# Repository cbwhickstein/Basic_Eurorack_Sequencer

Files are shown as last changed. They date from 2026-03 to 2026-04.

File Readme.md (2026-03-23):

# Eurorack CD4017 10-Steps Sequencer
This Repo containes a simple 10 Step sequencer for the Eurorack Modular standard.

## Schematic
./KiCad/Sequencer/Schematic.pdf


## PCB
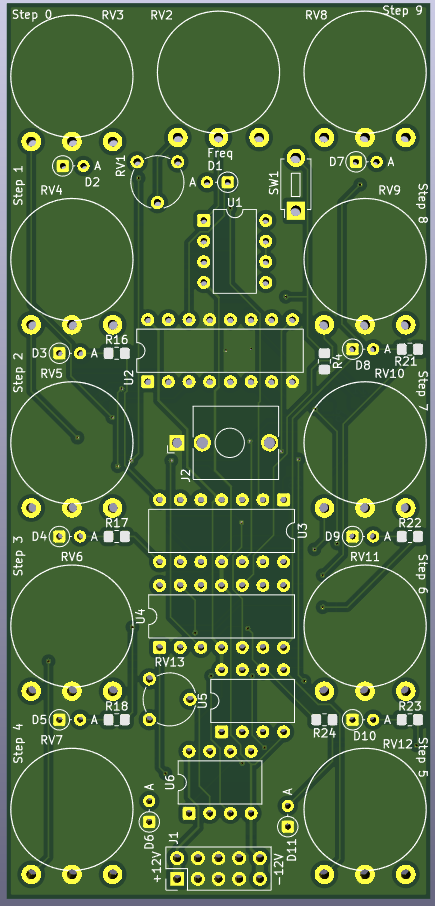
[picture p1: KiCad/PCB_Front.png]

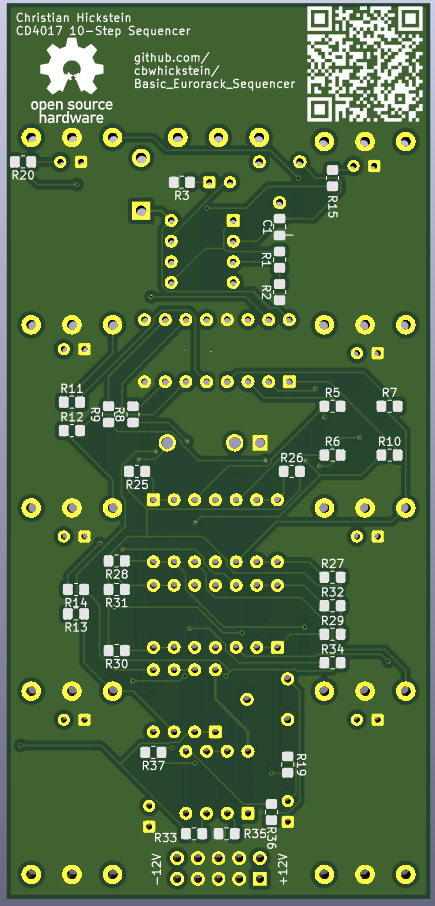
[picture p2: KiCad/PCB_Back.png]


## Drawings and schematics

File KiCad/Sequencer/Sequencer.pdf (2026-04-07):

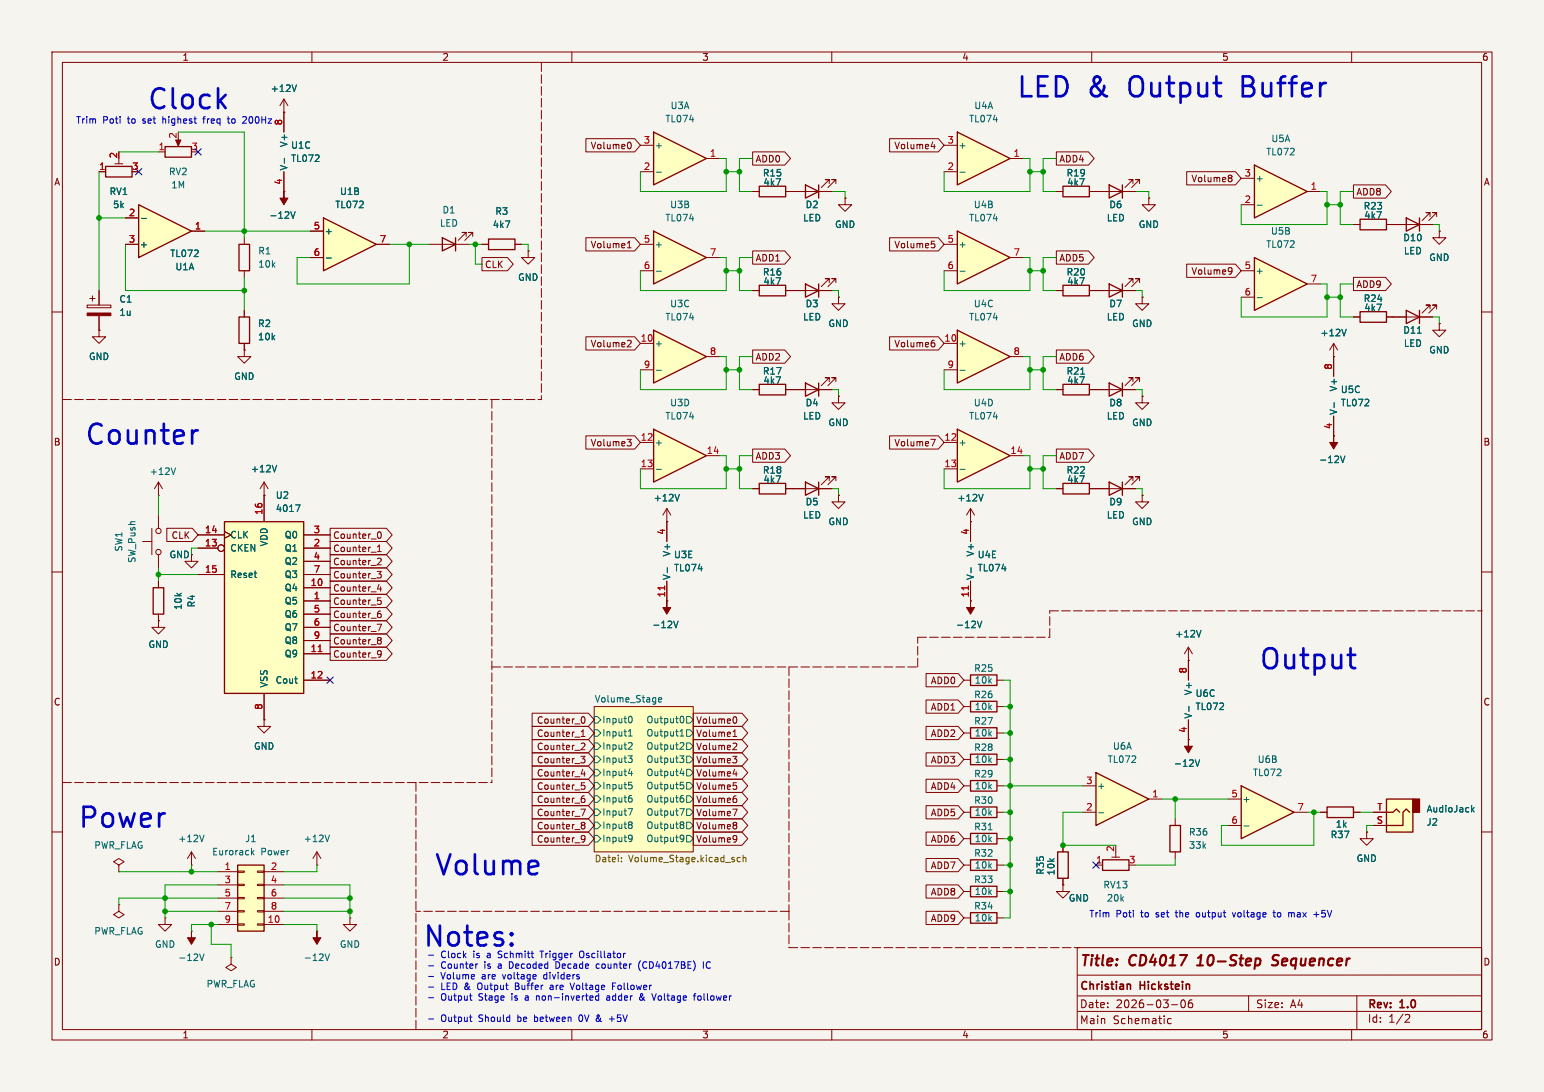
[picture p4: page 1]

Trim Poti to set highest freq to 200Hz

- Output Should be between 0V & +5V Counter

8 Q0 3 Q1 2 Q2 4 Q3 7 Q4 10 Q5 1 Q6 5 Q7 6 Q8 9 Q9 11 Cout 12 GND 10k R4 GND GND

Trim Poti to set the output voltage to max +5V Output

- Clock is a Schmitt Trigger Oscillator
- Volume are voltage dividers
- LED & Output Buffer are Voltage Follower

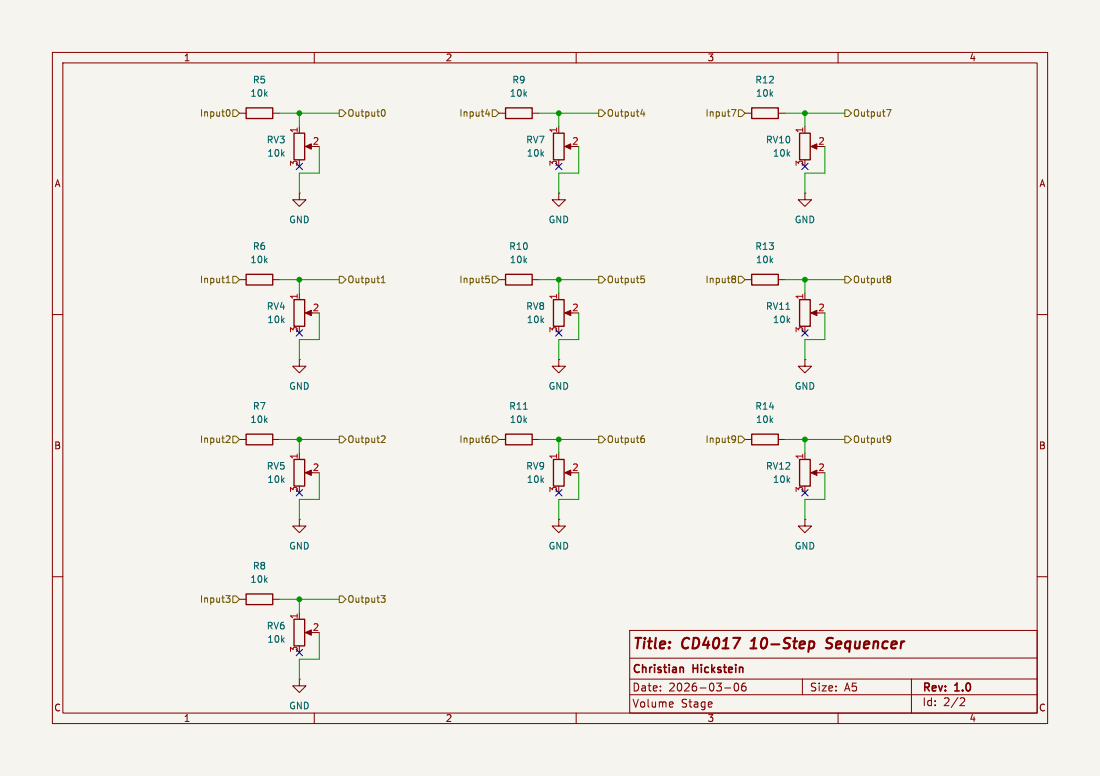
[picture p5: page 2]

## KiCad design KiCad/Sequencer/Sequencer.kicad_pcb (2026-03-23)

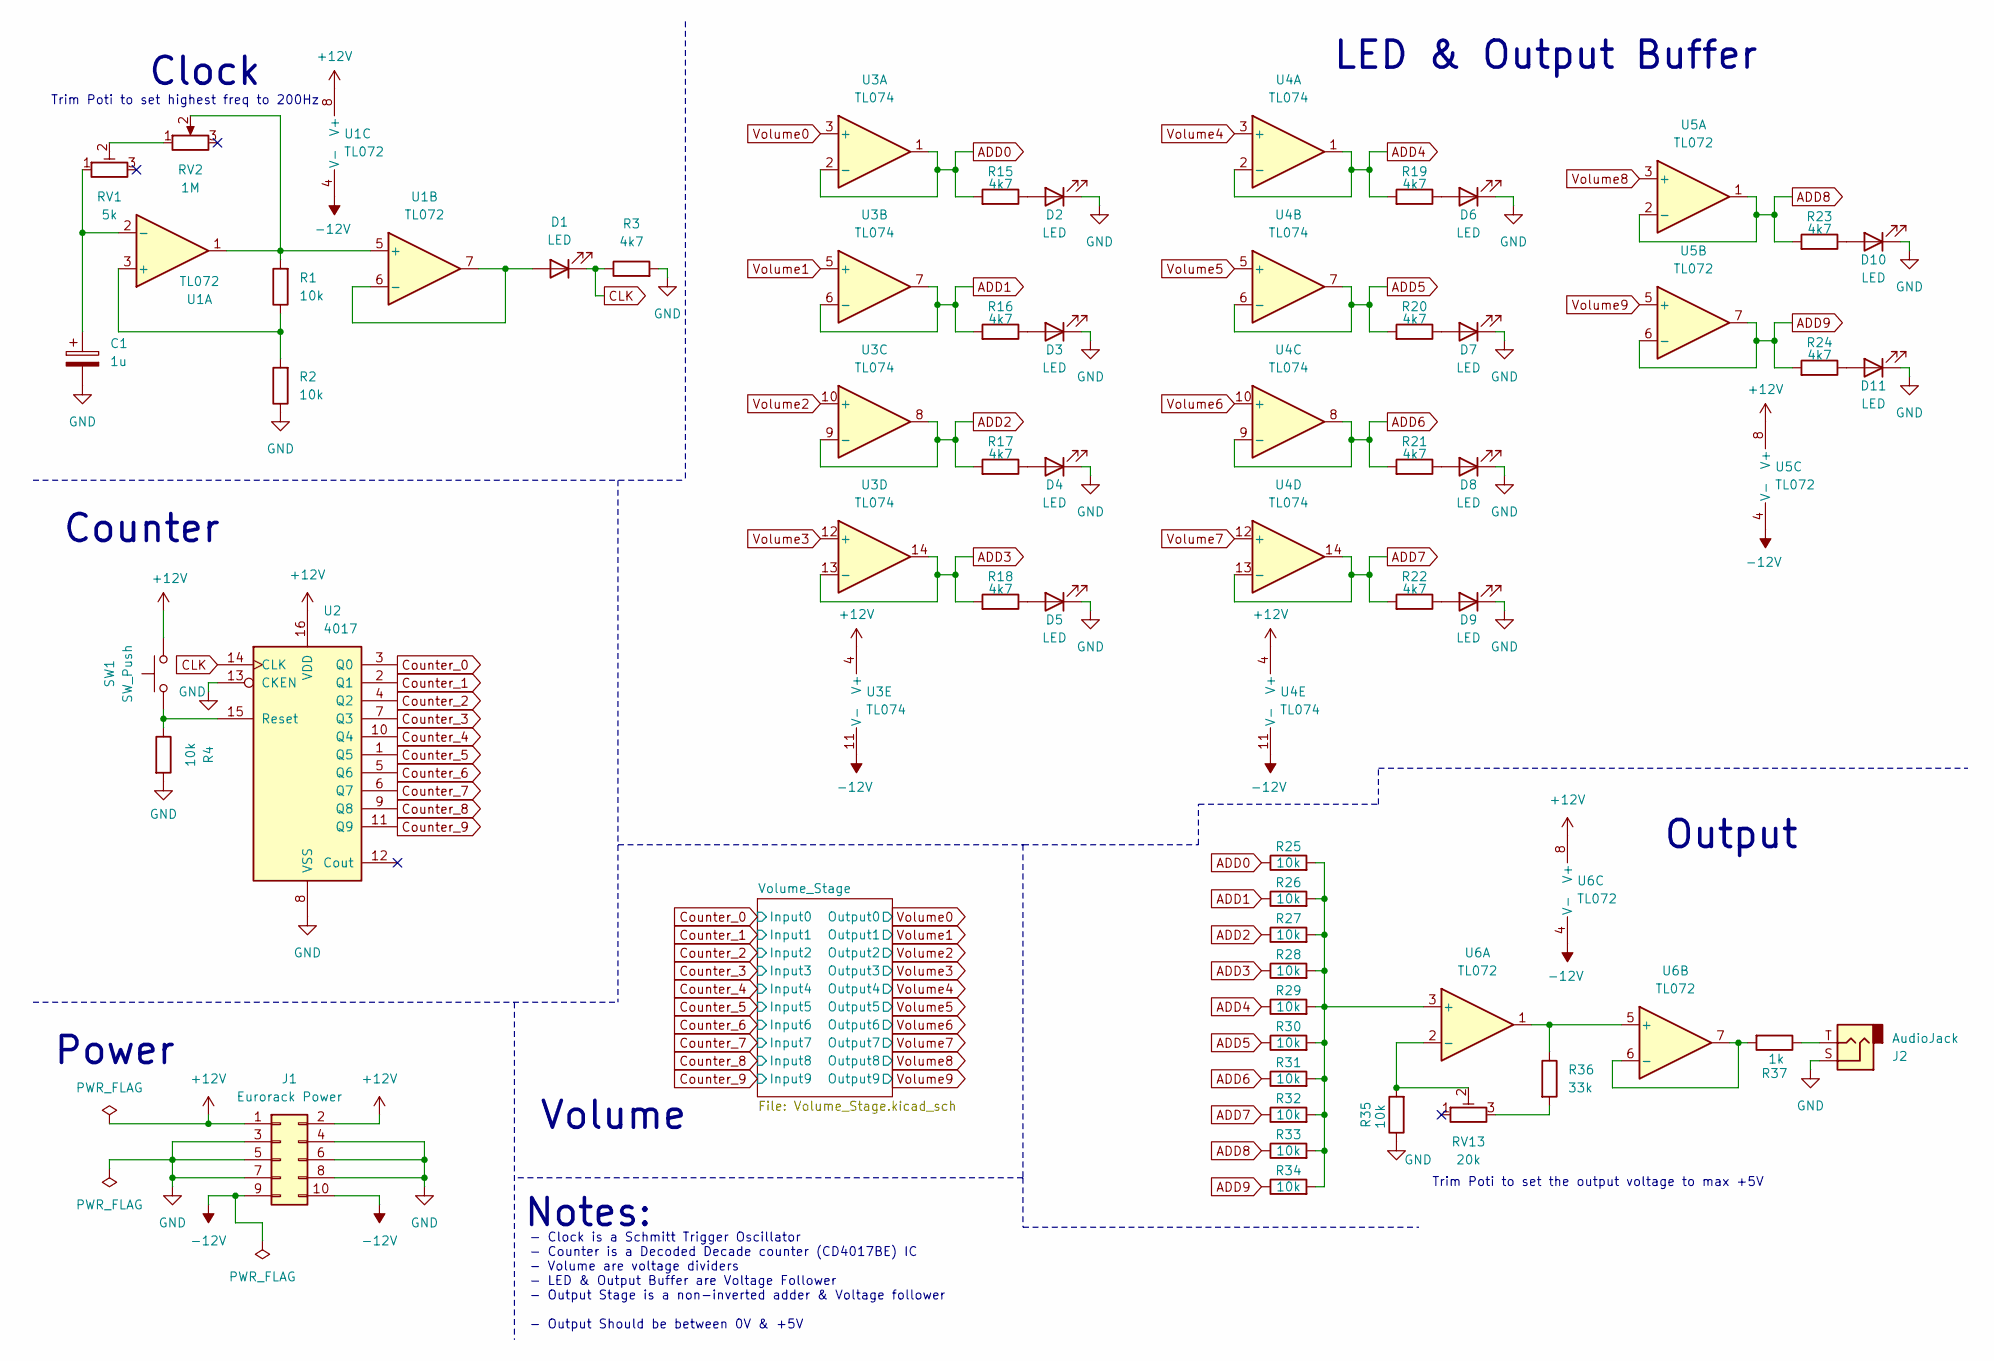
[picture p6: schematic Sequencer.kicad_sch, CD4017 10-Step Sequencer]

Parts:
C1: 1u; C_0805_2012Metric_Pad1.18x1.45mm_HandSolder
D1, D2, D3, D4, D5, D6, D7, D8, D9, D10, D11: LED; D_DO-34_SOD68_P2.54mm_Vertical_AnodeUp
J1: Eurorack Power; PinHeader_2x05_P2.54mm_Vertical
J2: AudioJack; Jack_3.5mm_QingPu_WQP-PJ398SM_Vertical_CircularHoles
R1, R2, R4, R25, R26, R27, R28, R29, R30, R31, R32, R33, R34, R35: 10k; R_0805_2012Metric_Pad1.20x1.40mm_HandSolder
R3, R15, R16, R17, R18, R19, R20, R21, R22, R23, R24: 4k7; R_0805_2012Metric_Pad1.20x1.40mm_HandSolder
R36: 33k; R_0805_2012Metric_Pad1.20x1.40mm_HandSolder
R37: 1k; R_0805_2012Metric_Pad1.20x1.40mm_HandSolder
RV1: 5k; Potentiometer_Piher_PT-6-V_Vertical
RV2: 1M; Potis
RV13: 20k; Potentiometer_Piher_PT-6-V_Vertical
SW1: SW_Push; SW_PUSH_1P1T_6x3.5mm_H4.3_APEM_MJTP1243
U1, U5, U6: TL072; DIP-8_W7.62mm
U2: 4017; DIP-16_W7.62mm
U3, U4: TL074; DIP-14_W7.62mm

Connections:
+12V: J1.1, J1.2, SW1.1, U1.8 (V+), U2.16 (VDD), U3.4 (V+), U4.4 (V+), U5.8 (V+), U6.8 (V+)
-12V: J1.9, J1.10, U1.4 (V-), U3.11 (V-), U4.11 (V-), U5.4 (V-), U6.4 (V-)
ADD0: R15.2, R25.1, U3.1, U3.2 (-)
ADD1: R16.2, R26.1, U3.6 (-), U3.7
ADD2: R17.2, R27.1, U3.8, U3.9 (-)
ADD3: R18.2, R28.1, U3.13 (-), U3.14
ADD4: R19.2, R29.1, U4.1, U4.2 (-)
ADD5: R20.2, R30.1, U4.6 (-), U4.7
ADD6: R21.2, R31.1, U4.8, U4.9 (-)
ADD7: R22.2, R32.1, U4.13 (-), U4.14
ADD8: R23.2, R33.1, U5.1, U5.2 (-)
ADD9: R24.2, R34.1, U5.6 (-), U5.7
CLK: D1.1 (K), R3.1, U2.14 (CLK)
Counter_0: U2.3 (Q0); also elsewhere on the board
Counter_1: U2.2 (Q1); also elsewhere on the board
Counter_2: U2.4 (Q2); also elsewhere on the board
Counter_3: U2.7 (Q3); also elsewhere on the board
Counter_4: U2.10 (Q4); also elsewhere on the board
Counter_5: U2.1 (Q5); also elsewhere on the board
Counter_6: U2.5 (Q6); also elsewhere on the board
Counter_7: U2.6 (Q7); also elsewhere on the board
Counter_8: U2.9 (Q8); also elsewhere on the board
Counter_9: U2.11 (Q9); also elsewhere on the board
GND: C1.2, D2.1 (K), D3.1 (K), D4.1 (K), D5.1 (K), D6.1 (K), D7.1 (K), D8.1 (K), D9.1 (K), D10.1 (K), D11.1 (K), J1.3, J1.4, J1.5, J1.6, J1.7, J1.8, J2.S, R2.1, R3.2, R4.2, R35.1, U2.8 (VSS), U2.13 (CKEN); also elsewhere on the board
unnamed: D1.2 (A), U1.6 (-), U1.7
unnamed: D2.2 (A), R15.1
unnamed: D3.2 (A), R16.1
unnamed: D4.2 (A), R17.1
unnamed: D5.2 (A), R18.1
unnamed: D6.2 (A), R19.1
unnamed: D7.2 (A), R20.1
unnamed: D8.2 (A), R21.1
unnamed: D9.2 (A), R22.1
unnamed: D10.2 (A), R23.1
unnamed: D11.2 (A), R24.1
unnamed: J2.T, R37.1
unnamed: R36.2, RV13.3
unnamed: RV1.2, RV2.1
unnamed: R1.1, R2.2, U1.3 (+)
unnamed: C1.1, RV1.1, U1.2 (-)
unnamed: R1.2, RV2.2, U1.1, U1.5 (+)
unnamed: R4.1, SW1.2, U2.15 (Reset)
unnamed: R25.2, R26.2, R27.2, R28.2, R29.2, R30.2, R31.2, R32.2, R33.2, R34.2, U6.3 (+)
unnamed: R35.2, RV13.2, U6.2 (-)
unnamed: R36.1, U6.1, U6.5 (+)
unnamed: R37.2, U6.6 (-), U6.7
Volume0: U3.3 (+); also elsewhere on the board
Volume1: U3.5 (+); also elsewhere on the board
Volume2: U3.10 (+); also elsewhere on the board
Volume3: U3.12 (+); also elsewhere on the board
Volume4: U4.3 (+); also elsewhere on the board
Volume5: U4.5 (+); also elsewhere on the board
Volume6: U4.10 (+); also elsewhere on the board
Volume7: U4.12 (+); also elsewhere on the board
Volume8: U5.3 (+); also elsewhere on the board
Volume9: U5.5 (+); also elsewhere on the board

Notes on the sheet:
Volume
Clock
Notes:
LED & Output Buffer
Counter
Trim Poti to set highest freq to 200Hz
- Clock is a Schmitt Trigger Oscillator - Counter is a Decoded Decade counter (CD4017BE) IC - Volume are voltage dividers - LED & Output Buffer are Voltage Follower - Output Stage is a non-inverted adder & Voltage follower - Output Should be between 0V & +5V
Power
Output
Trim Poti to set the output voltage to max +5V

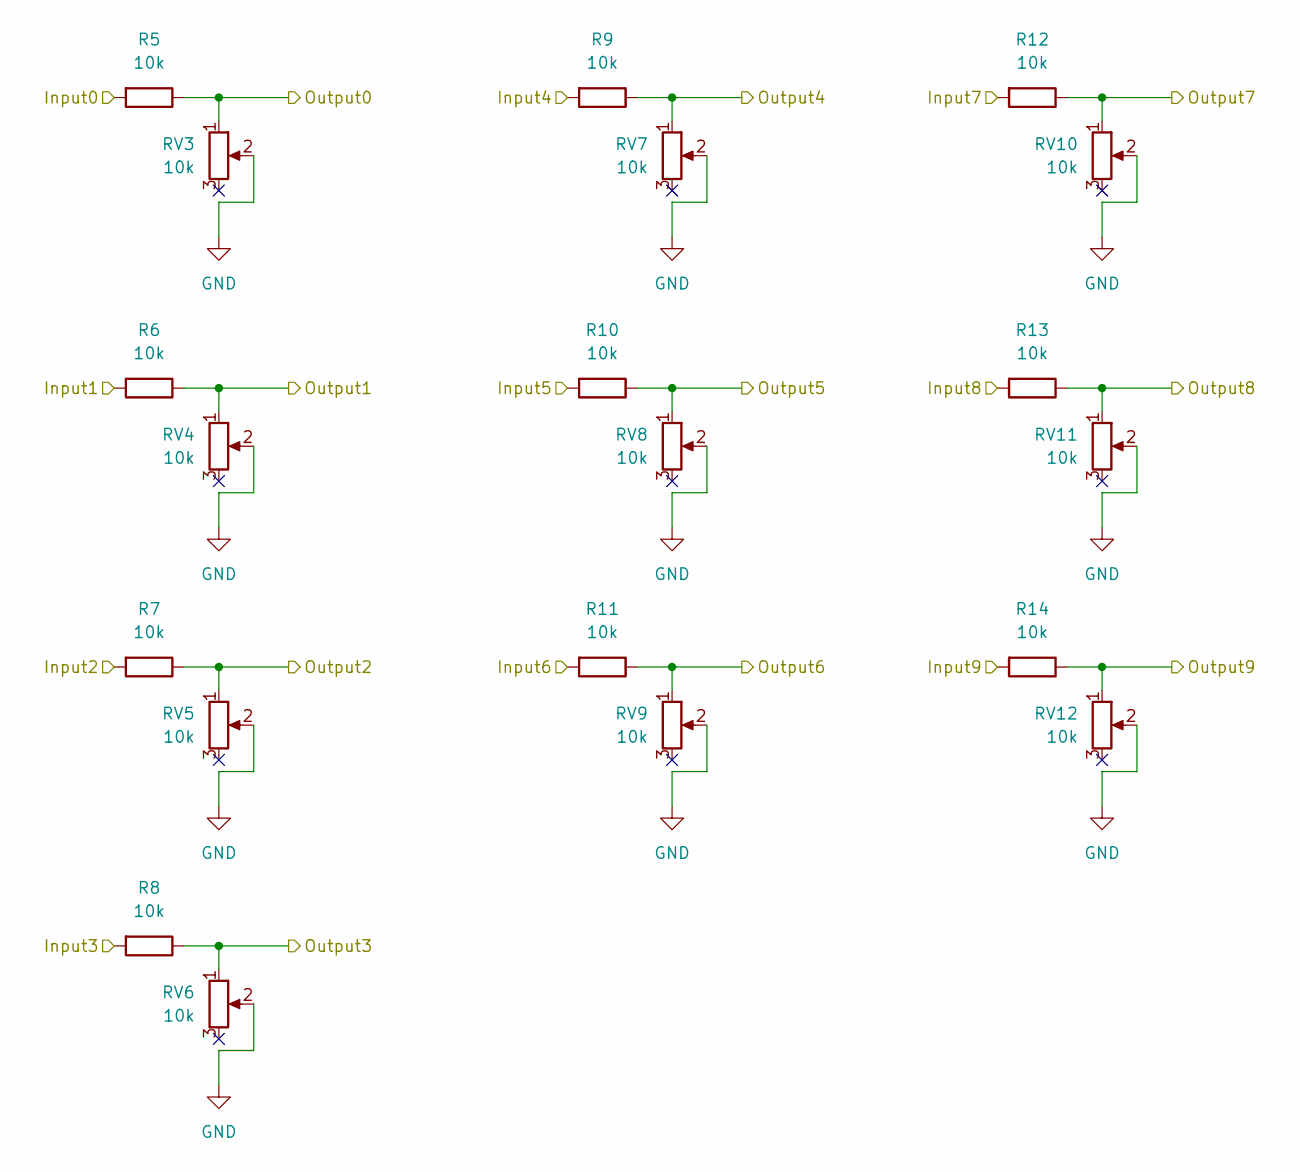
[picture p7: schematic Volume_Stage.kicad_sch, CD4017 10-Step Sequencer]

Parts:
R5, R6, R7, R8, R9, R10, R11, R12, R13, R14: 10k; R_0805_2012Metric_Pad1.20x1.40mm_HandSolder
RV3, RV4, RV5, RV6, RV7, RV8, RV9, RV10, RV11, RV12: 10k; Potis

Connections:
Counter_0: R5.2; also elsewhere on the board
Counter_1: R6.2; also elsewhere on the board
Counter_2: R7.2; also elsewhere on the board
Counter_3: R8.2; also elsewhere on the board
Counter_4: R9.2; also elsewhere on the board
Counter_5: R10.2; also elsewhere on the board
Counter_6: R11.2; also elsewhere on the board
Counter_7: R12.2; also elsewhere on the board
Counter_8: R13.2; also elsewhere on the board
Counter_9: R14.2; also elsewhere on the board
GND: RV3.2, RV4.2, RV5.2, RV6.2, RV7.2, RV8.2, RV9.2, RV10.2, RV11.2, RV12.2; also elsewhere on the board
Volume0: R5.1, RV3.1; also elsewhere on the board
Volume1: R6.1, RV4.1; also elsewhere on the board
Volume2: R7.1, RV5.1; also elsewhere on the board
Volume3: R8.1, RV6.1; also elsewhere on the board
Volume4: R9.1, RV7.1; also elsewhere on the board
Volume5: R10.1, RV8.1; also elsewhere on the board
Volume6: R11.1, RV9.1; also elsewhere on the board
Volume7: R12.1, RV10.1; also elsewhere on the board
Volume8: R13.1, RV11.1; also elsewhere on the board
Volume9: R14.1, RV12.1; also elsewhere on the board

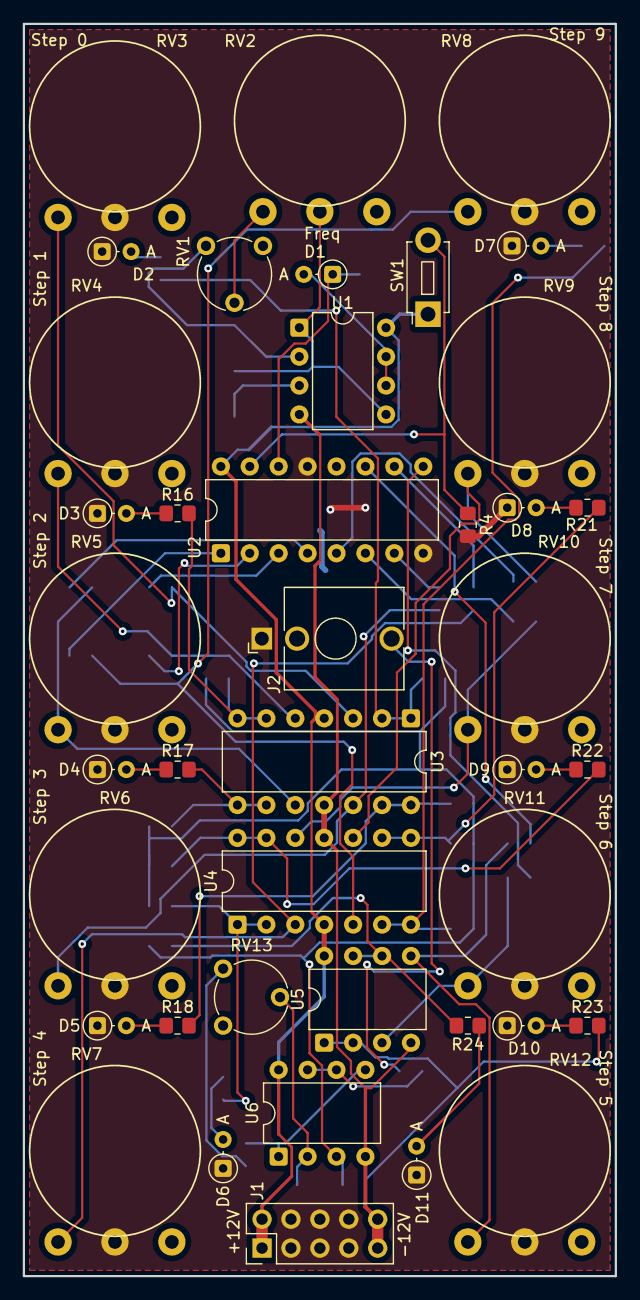
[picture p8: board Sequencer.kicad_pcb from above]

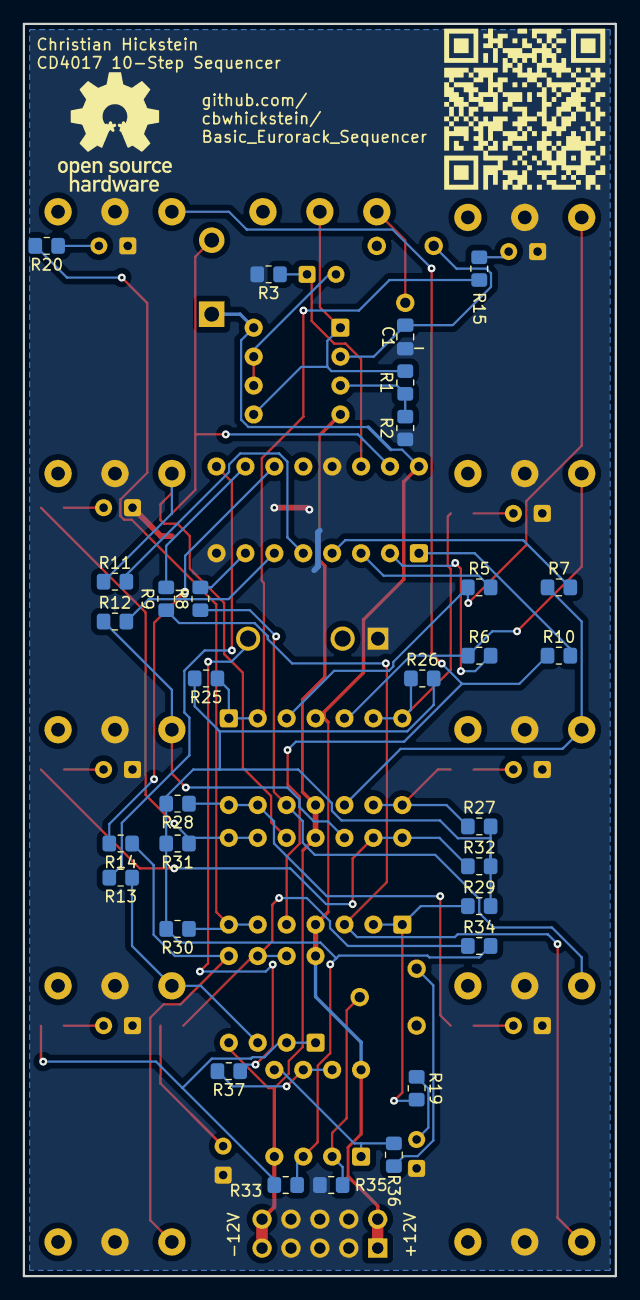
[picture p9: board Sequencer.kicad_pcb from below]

Board: 2 copper layers, 52.0 x 110.0 mm, 71 parts (30 on the bottom side), 56 nets.

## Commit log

2026-03-06 Finished Sequencer Schematic
    [Sequencer.kicad_pcb, Sequencer.kicad_sch, Volume_Stage.kicad_sch]
2026-03-16 V1.0 Schematic Finished
    [Sequencer.kicad_sch, Volume_Stage.kicad_sch]
2026-03-23 Finished Version 1.0 of PCB
    [Sequencer.kicad_pcb, Sequencer.kicad_sch, Volume_Stage.kicad_sch]
2026-04-07 Version 1.0: Schematic Finished
